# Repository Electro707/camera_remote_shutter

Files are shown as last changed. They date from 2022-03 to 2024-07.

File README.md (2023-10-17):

# Camera Remote Shutter Project
#### Rev 1.0-alpha

This is an open-source camera remote shutter.

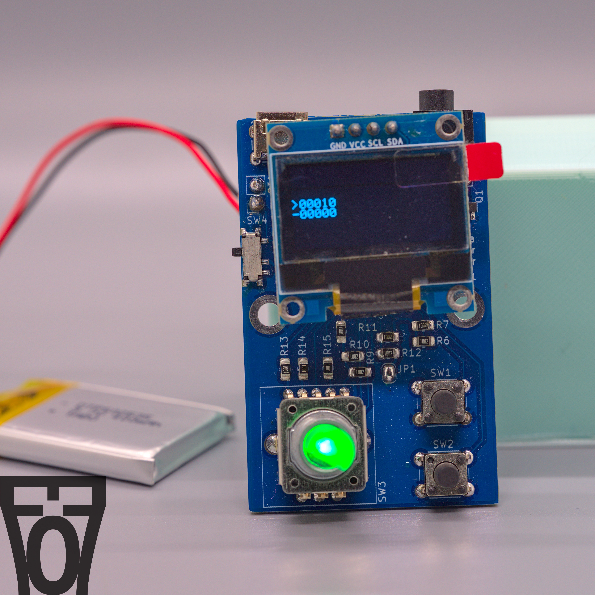
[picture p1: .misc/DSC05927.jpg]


## Enclosure
There is a work-in-progress enclosure for the PCB under the [CAD](CAD) folder. The enclosure is made with FreeCAD 0.20.

## Firmware
The firmware for this project is in the `AVR` folder. To build the code, simply run

```
make
```

This will generate a binary to upload to the MCU. To program the board, you can connect an Arduino Uno acting as an ISP device to the 3x2 connector on the board (J2). Then you can use the following make argument to upload with AVRDude. The port is asssumed to be `/dev/ttyUSB0`, so if that is different you can change the makefile.

```
make program
```

## KiCAD 3D Models
The 3D models for some components in the directory `PCB/3d_model/` are not included due to licensing reasons. You can grab the step files yourself and put it in that directory from the manufacturer. The models are
- 12CE3H26F12T24.stp
- CUI_DEVICES_SJ-2509N.step

# License
This project is licensed under GPLv3. See [LICENSE.md](LICENSE.md) for details.

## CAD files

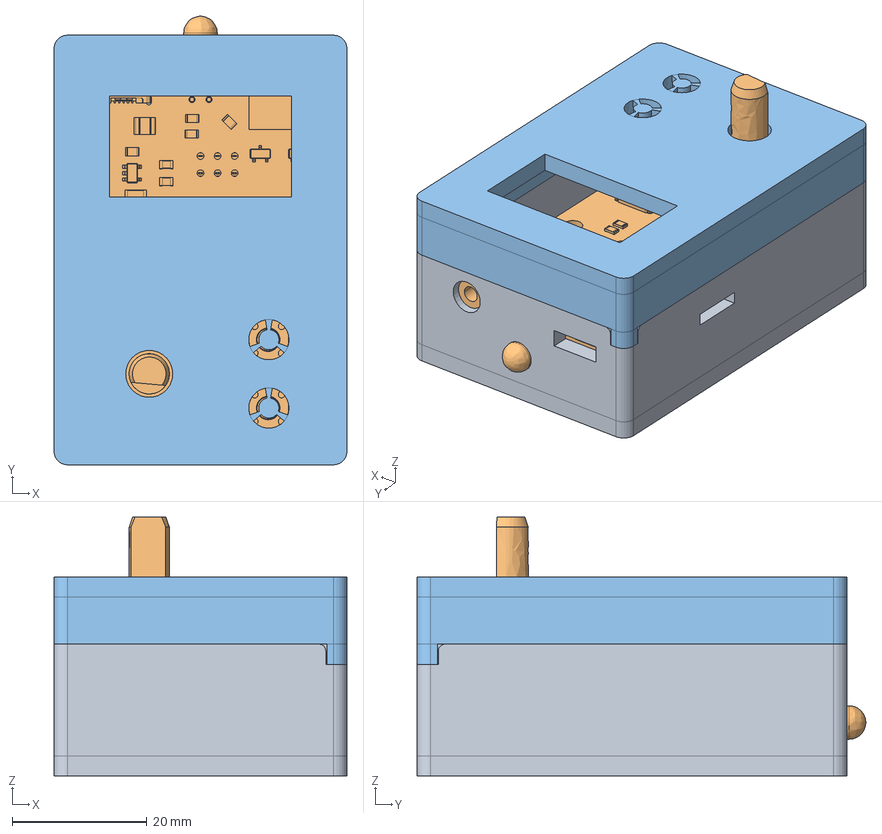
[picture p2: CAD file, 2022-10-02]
CAD/Assembly.FCStd
43.6 x 66.7 x 38.5 mm
MainBody_001
PCB1_001
TopCover_001

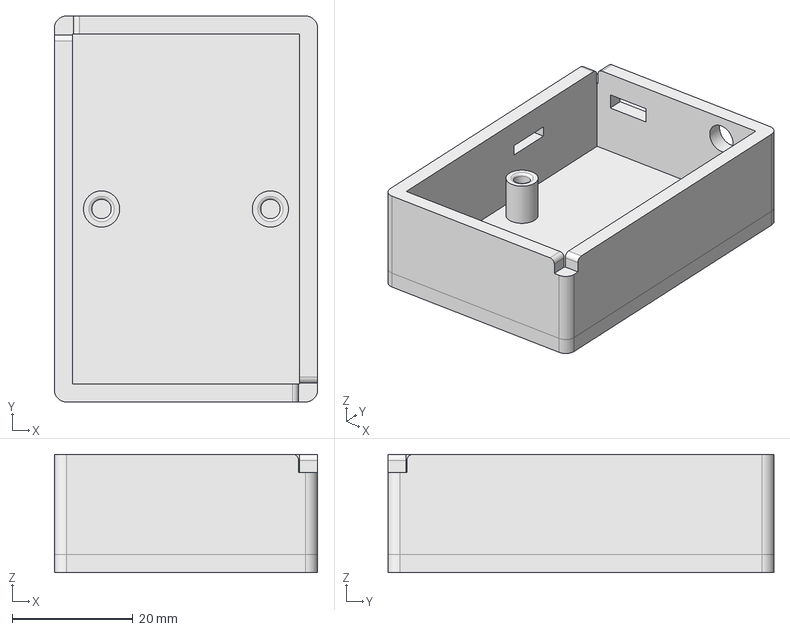
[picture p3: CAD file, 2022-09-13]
CAD/MainBody.FCStd
43.6 x 63.9 x 19.6 mm

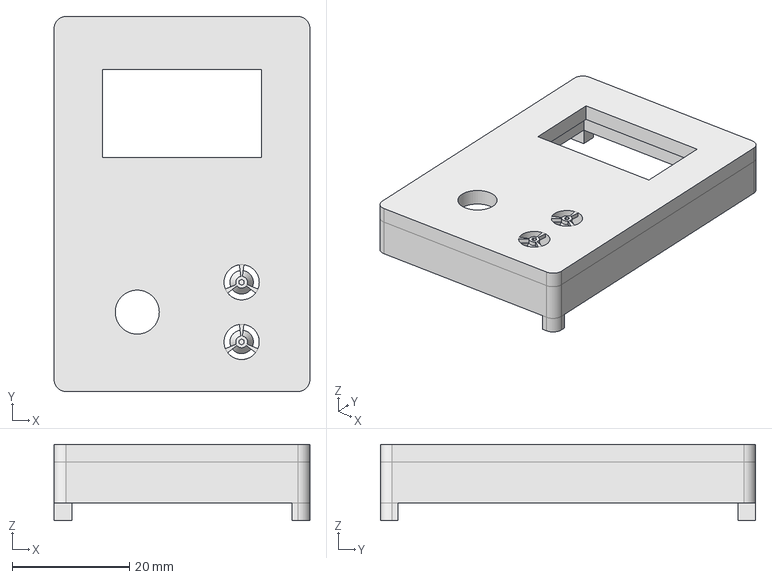
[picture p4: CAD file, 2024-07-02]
CAD/TopCover.FCStd
43.6 x 63.9 x 13.0 mm

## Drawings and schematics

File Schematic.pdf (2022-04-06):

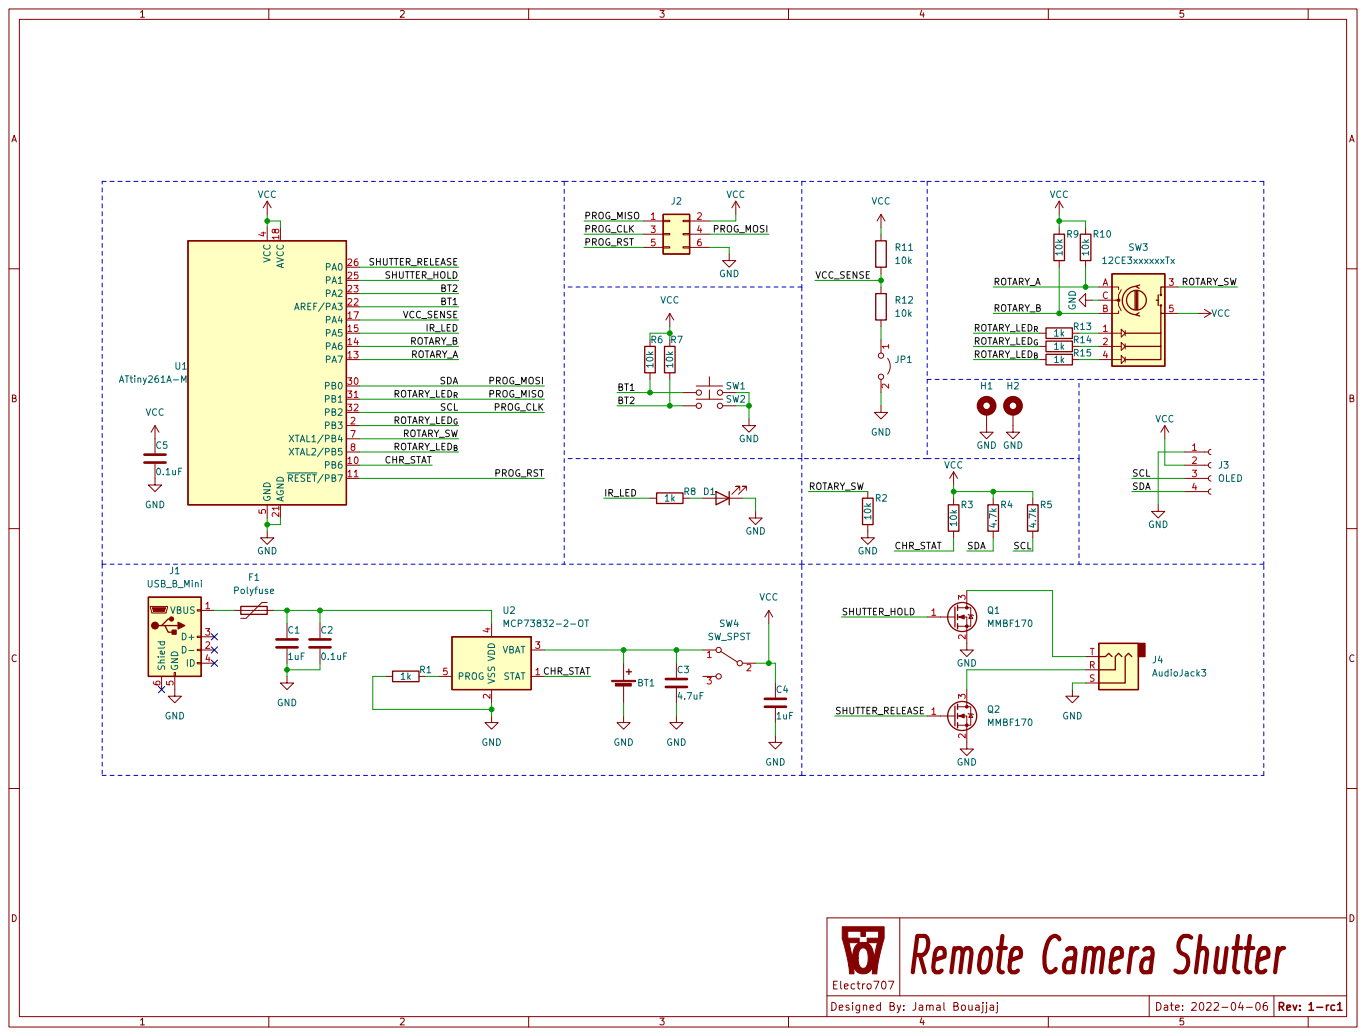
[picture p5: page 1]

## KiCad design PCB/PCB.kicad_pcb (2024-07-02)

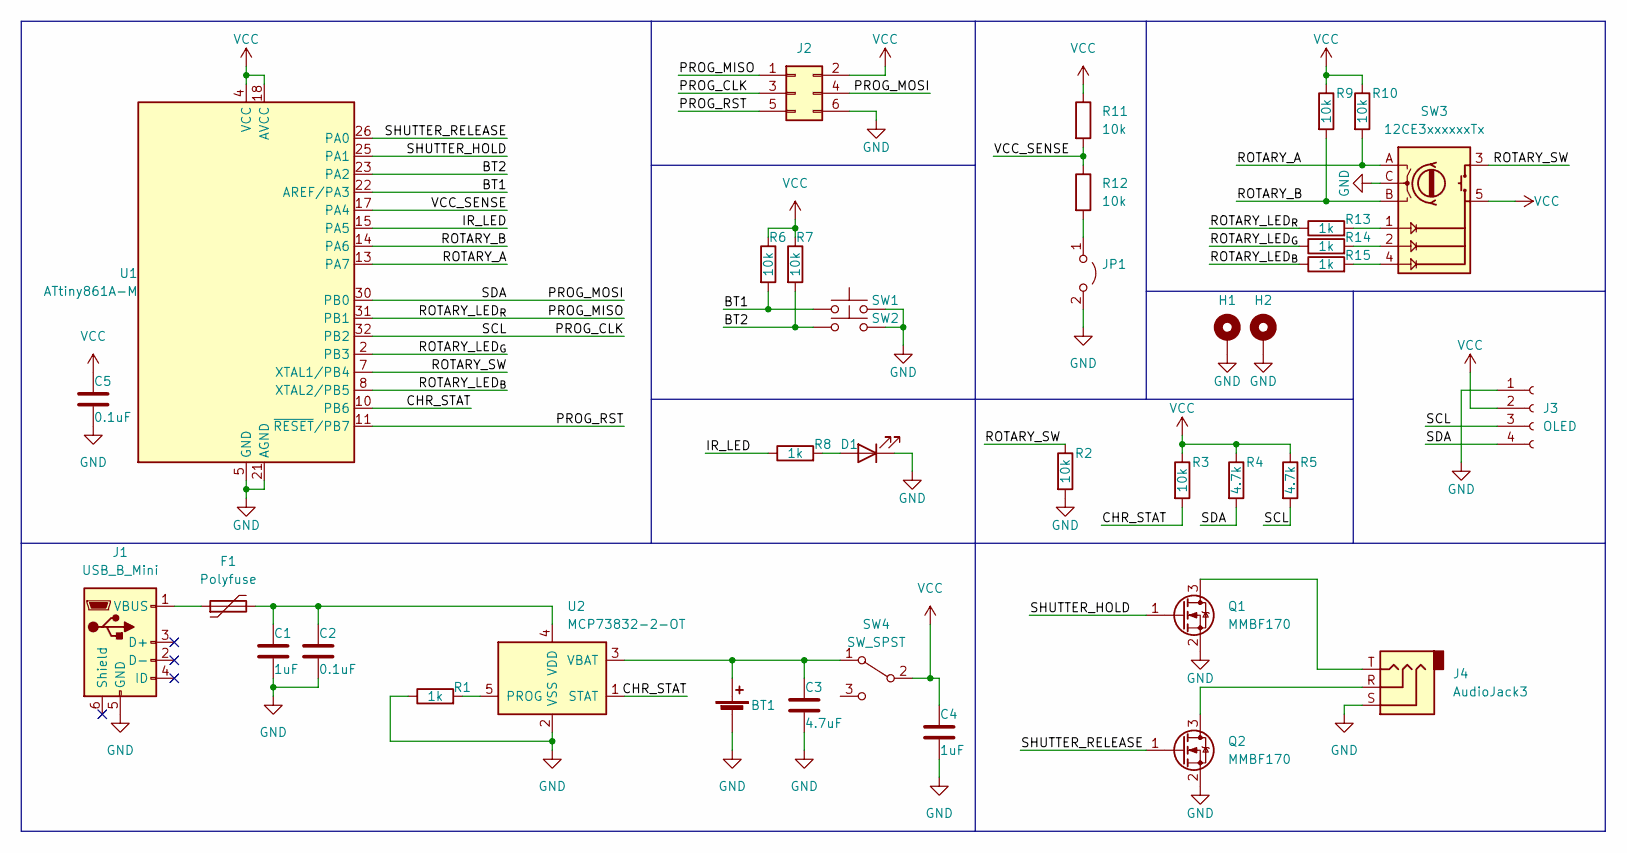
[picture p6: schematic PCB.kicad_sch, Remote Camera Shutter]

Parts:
BT1: Battery_Cell; PinSocket_1x02_P2.54mm_Vertical
C1, C4: 1uF; C_0805_2012Metric_Pad1.18x1.45mm_HandSolder
C2, C5: 0.1uF; C_0805_2012Metric_Pad1.18x1.45mm_HandSolder
C3: 4.7uF; C_1206_3216Metric_Pad1.33x1.80mm_HandSolder
D1: LED; LED_D5.0mm_Horizontal_O3.81mm_Z3.0mm
F1: Polyfuse; Fuse_1210_3225Metric_Pad1.42x2.65mm_HandSolder
H1, H2: MountingHole_Pad; MountingHole_3.2mm_M3_DIN965_Pad
J1: USB_B_Mini; USB_Micro-B_Wuerth_629105150521
J2: Conn_02x03_Odd_Even; PinSocket_2x03_P2.54mm_Vertical
J3: OLED; PinSocket_1x04_P2.54mm_Vertical
J4: AudioJack3; MJ1-2503A
JP1: Jumper_2_Open; SolderJumper-2_P1.3mm_Open_RoundedPad1.0x1.5mm
Q1, Q2: MMBF170; SOT-23
R1, R8, R13, R14, R15: 1k; R_0805_2012Metric_Pad1.20x1.40mm_HandSolder
R2, R3, R6, R7, R9, R10, R11, R12: 10k; R_0805_2012Metric_Pad1.20x1.40mm_HandSolder
R4, R5: 4.7k; R_0805_2012Metric_Pad1.20x1.40mm_HandSolder
SW1, SW2: SW_Push; SW_PUSH_6mm
SW3: 12CE3xxxxxxTx; 12CE3KxxxxxTx
SW4: SW_SPST; SW_SPDT_PCM12
U1: ATtiny861A-M; QFN-32-1EP_5x5mm_P0.5mm_EP3.1x3.1mm
U2: MCP73832-2-OT; SOT-23-5

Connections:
/BT1: R6.2, SW1.1, U1.22 (AREF/PA3)
/BT2: R7.2, SW2.1, U1.23 (PA2)
/CHR_STAT: R3.2, U1.10 (PB6), U2.1 (STAT)
/IR_LED: R8.1, U1.15 (PA5)
/PROG_CLK: J2.3, J3.3, R5.2, U1.32 (PB2)
/PROG_MISO: J2.1, R13.1, U1.31 (PB1)
/PROG_MOSI: J2.4, J3.4, R4.2, U1.30 (PB0)
/PROG_RST: J2.5, U1.11 (~RESET/PB7)
/ROTARY_A: R10.2, SW3.A, U1.13 (PA7)
/ROTARY_B: R9.2, SW3.B, U1.14 (PA6)
/ROTARY_LED_{B}: R15.1, U1.8 (XTAL2/PB5)
/ROTARY_LED_{G}: R14.1, U1.2 (PB3)
/ROTARY_SW: R2.1, SW3.3 (S1), U1.7 (XTAL1/PB4)
/SHUTTER_HOLD: Q1.1 (G), U1.25 (PA1)
/SHUTTER_RELEASE: Q2.1 (G), U1.26 (PA0)
/VCC_SENSE: R11.2, R12.1, U1.17 (PA4)
GND: BT1.2 (-), C1.2, C2.2, C3.2, C4.2, C5.2, D1.1 (K), H1.1, H2.1, J1.5 (GND), J2.6, J3.1, J4.S, JP1.2 (B), Q1.2 (S), Q2.2 (S), R1.1, R2.2, SW1.2, SW2.2, SW3.C, U1.5 (GND), U1.21 (AGND), U1.33 (GND), U2.2 (VSS)
unnamed: BT1.1 (+), C3.1, SW4.1 (A), U2.3 (VBAT)
unnamed: D1.2 (A), R8.2
unnamed: F1.1, J1.1 (VBUS)
unnamed: JP1.1 (A), R12.2
unnamed: J4.T, Q1.3 (D)
unnamed: J4.R, Q2.3 (D)
unnamed: R15.2, SW3.4 (L_B)
unnamed: R14.2, SW3.2 (L_G)
unnamed: R13.2, SW3.1 (L_R)
unnamed: R1.2, U2.5 (PROG)
unnamed: C1.1, C2.1, F1.2, U2.4 (VDD)
VCC: C4.1, C5.1, J2.2, J3.2, R3.1, R4.1, R5.1, R6.1, R7.1, R9.1, R10.1, R11.1, SW3.5 (COMM), SW4.2 (B), U1.4 (VCC), U1.18 (AVCC)

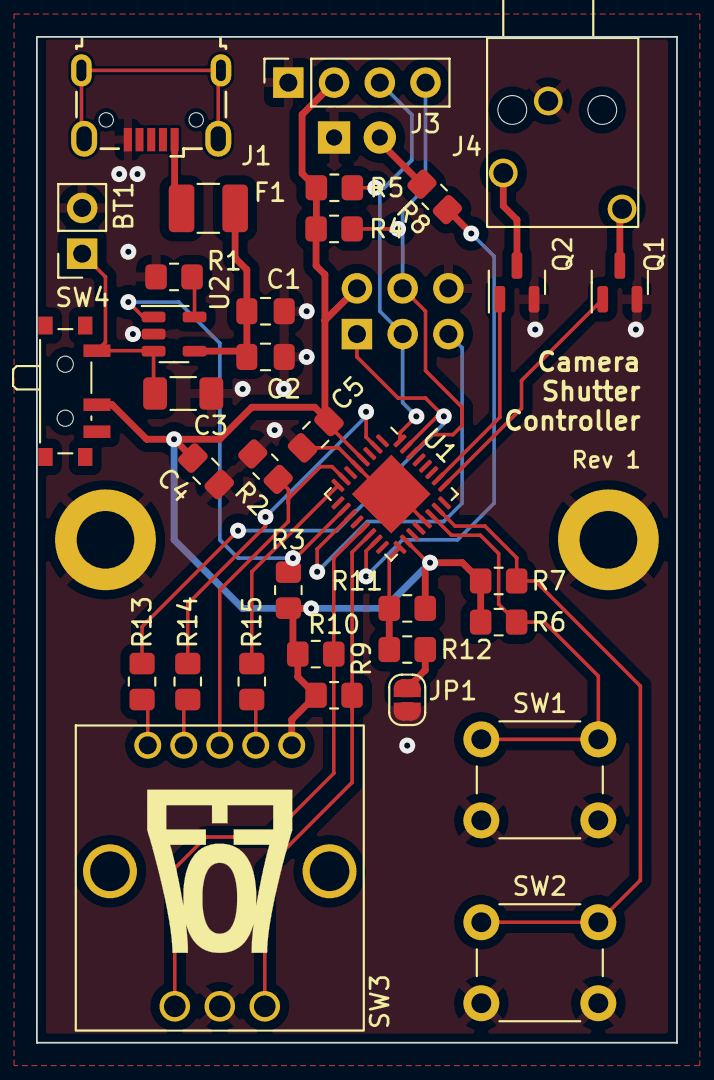
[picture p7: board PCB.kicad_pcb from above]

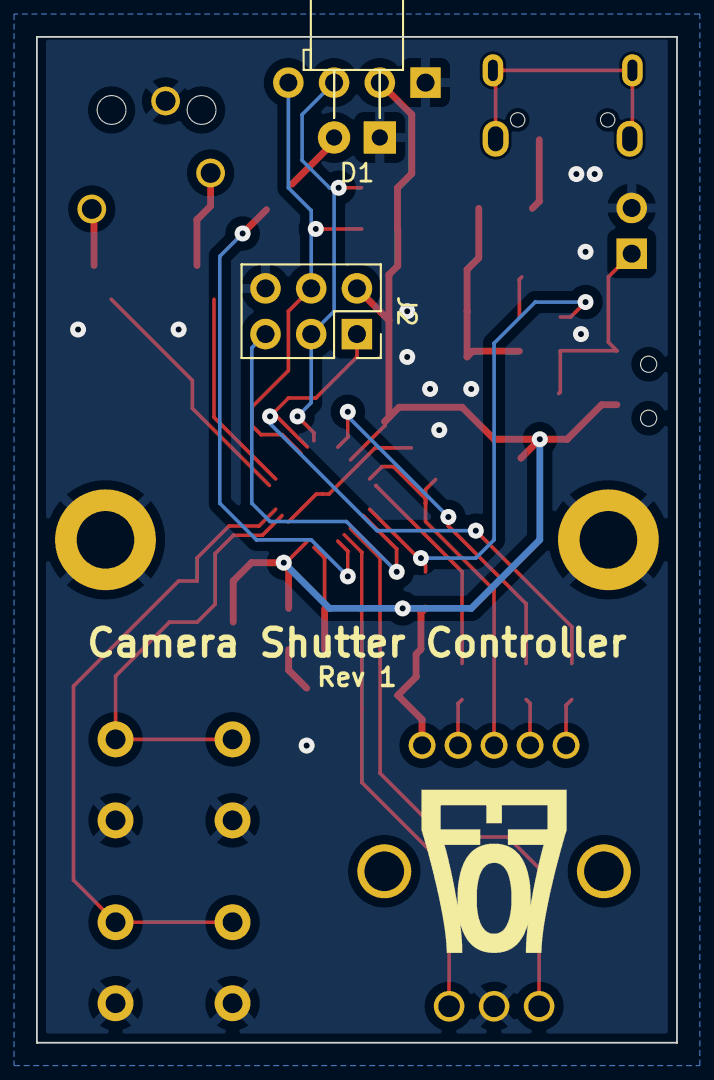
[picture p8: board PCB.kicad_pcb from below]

Board: 2 copper layers, 35.6 x 55.9 mm, 38 parts (2 on the bottom side), 29 nets.

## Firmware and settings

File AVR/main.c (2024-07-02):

/**
 * Camera Shutter Control Project
 * By Electro707, 2023
 *
 * This is the main firmware file for the camera shutter board.
 *
 * This program is free software: you can redistribute it and/or modify it under the terms of the
 * GNU General Public License as published by the Free Software Foundation, either version 3 of the
 * License, or (at your option) any later version.
 */
#define F_CPU 8000000       // CPU clock cycles
#define N_DIGITS    5

#include <stdbool.h>
#include <avr/io.h>
#include <util/delay.h>
#include <avr/interrupt.h>
#include <stdlib.h>
#include "USI_TWI_Master.h"
#include "oled.h"


/* LED Related Macros */
#define LED_PORT PORTB
#define LED_RED_PIN (1 << 1)
#define LED_GREEN_PIN (1 << 3)
#define LED_BLUE_PIN (1 << 5)
#define TURN_ON_RED_LED (LED_PORT &= ~LED_RED_PIN)
#define TURN_ON_GREEN_LED (LED_PORT &= ~LED_GREEN_PIN)
#define TURN_ON_BLUE_LED (LED_PORT &= ~LED_BLUE_PIN)
#define TURN_OFF_RED_LED (LED_PORT |= LED_RED_PIN)
#define TURN_OFF_GREEN_LED (LED_PORT |= LED_GREEN_PIN)
#define TURN_OFF_BLUE_LED (LED_PORT |= LED_BLUE_PIN)
#define TURN_OFF_ALL_LED TURN_OFF_RED_LED; TURN_OFF_GREEN_LED; TURN_OFF_BLUE_LED
#define TURN_ON_CYAN TURN_ON_GREEN_LED; TURN_ON_BLUE_LED
/* Rotary Encoder and Button Read Macros */
#define READ_ROTARY_ENCODER_BIT ((PINA >> 6) & 0b11)
#define READ_ROTARY_ENCODER_BUTTON ((PINB >> 4) & 0b1)
#define READ_TRIGGER_BUTTON ((PINA >> 2) & 0b1)
#define READ_MODE_BUTTON ((PINA >> 3) & 0b1)
/* Trigger Related Macros */
#define TRIGGER_ON PORTA |= (1 << 1); PORTA |= (1 << 0)
#define TRIGGER_OFF PORTA &= ~(1 << 1); PORTA &= ~(1 << 0)

#define RESET_TIMER TCNT0H = 0; TCNT0L = 0

typedef enum{
    ROTARY_ENCODER_ROT_NOTHING = 0,
    ROTARY_ENCODER_ROT_CW = 1,
    ROTARY_ENCODER_ROT_CCW = 2,
}RotaryEncoderRotation_e;

typedef enum{
    TRIGGER_MODE_STANDBY = 0,               // standby, doing nothing
    TRIGGER_MODE_ARM,                       // arming, i.e waiting for trigger
    TRIGGER_MODE_TRIGGERED,                 // triggered the camera
    TRIGGER_MODE_WAITING_FOR_NEXT_PIC,      // waiting for the next picture in a multi picture arm
    TRIGGER_MODE_END,                       // end of trigger
}TriggerMode_e;

typedef enum{
    VARIABLE_CHANGE_TRT = 0,
    VARIABLE_CHANGE_TT,
    VARIABLE_CHANGE_NPIC,
    VARIABLE_CHANGE_INVERV,
}ChangeVariable_e;

typedef struct{
    RotaryEncoderRotation_e dir;
    bool bt_press;   // true if we pressed on the rotary encoder
}RotaryEncoderStruct_s;

/**
 * All trigger settings
 */
typedef struct{
    int16_t tt;         // Time to Trigger
    int16_t trt;        // Trigger Duration
    int16_t n_pic;      // number of pictures for timelapse mode
    int16_t tmlps_interv;   // The interval in seconds between different timelapse
}ShutterTriggerVars_s;

/**
 * Any system/run-time config
 */
typedef struct{
    TriggerMode_e mode;                 // the current trigger state machine mode
    ChangeVariable_e selected_to_change;     // index to variable we selected to be changed
    uint8_t selected_digit;         // index to digit to be changed
    int16_t *var_to_change;        // pointer to variable to change
}SystemConfig_s;

const int16_t tens_radix[5] = {1, 10, 100, 1000, 10000};

uint8_t blinking_led_var = 0;       // Variable used for blinking an LED during pre-trigger time
uint8_t timer_counter = 0;          // Counter used to make TIMER0 count once a second

int currBattBar = -1;
uint8_t isCharging = false;

uint8_t flagUpdateTrigTime = false;

ShutterTriggerVars_s shutter_trigger = {0};
ShutterTriggerVars_s old_shutter_trigger = {0};
RotaryEncoderStruct_s encoder_vars;
SystemConfig_s sys;

int text_to_ascii(uint16_t n, char *text);
void update_sutter_trigger_time(void);
void increment_change_var(void);
void start_arming(void);

void updateBatteryLevel(void);
void update_batt_indicator(void);

int main(void){
    uint8_t mode_bt_press = 0;
    int16_t change_by;
    // Clear variables
    shutter_trigger.tt = 0;
    shutter_trigger.trt = 10;
    sys.mode = TRIGGER_MODE_STANDBY;
    sys.selected_to_change = VARIABLE_CHANGE_TRT;
    sys.var_to_change = &shutter_trigger.trt;
    encoder_vars.bt_press = 0;

    // Setup GPIO
    DDRA = 0b00100011;
    DDRB = 0b00101111;

    PORTA |= (0b11 << 6);

    // Setup Timer 0 as the main ticker counter
    // 8Mhz / 256 / 250 = 125 Hz
    OCR0A = 250;
    TCCR0A = 1;
    TCCR0B = 0b100;
    TIMSK |= 1 << OCIE0A;

    // Clear Rotary Encoder LEDs
    TURN_OFF_RED_LED;
    TURN_OFF_GREEN_LED;
    TURN_OFF_BLUE_LED;
    
    // Enable Pin Change Interrupt for the important pins
    GIMSK |= (1 << PCIE1);
//     PCMSK0 |= (1 << PCINT2) | (1 << PCINT3) | (1 << PCINT6) | (1 << PCINT7);
//     PCMSK1 |= (1 << PCINT12);
    PCMSK0 |= (1 << PCINT6) | (1 << PCINT7);

    // enable the battery ADC input, ADC3
    ADMUX = (1 << REFS1) | (0b00011);      // select 2.56v reference, set mux to single ended PA4
    ADCSRB = (1 << REFS2);          // ref for 2.56v. free running mode
    DIDR0 = (1 << ADC3D);                          // disable digital input (only used for analog)
    ADCSRA = (0b111 << 5);       // enable adc and start conversion
    //ADCSRA = (1 << 7);       // enable adc

    
    USI_TWI_Master_Initialise();
    oled_init();
    // oled_send_text("CAMERA SHUTTER", 0);
    // oled_send_text("CONTROLLER REV 0.1", 1);
    update_sutter_trigger_time();
    oled_send_text("Shutter Speed:", 0);
    oled_send_text("T- Trigger:", 2);
    oled_send_text("Timelapse:", 4);

    oled_send_text_offset("# Pics:", 5, 0);
    oled_send_text_offset("Interv:", 5, 64);
    
    // Enable interrupts
    sei();
    
    while(1){
        _delay_ms(10);
        updateBatteryLevel();
        // only update if we are in standby
        if(sys.mode == TRIGGER_MODE_STANDBY){
            // if we turn the rotary encoder
            if(encoder_vars.dir != ROTARY_ENCODER_ROT_NOTHING){
                change_by = tens_radix[sys.selected_digit];
                if(encoder_vars.dir == ROTARY_ENCODER_ROT_CW){
                    TURN_ON_RED_LED;
                    TURN_OFF_GREEN_LED;
                    *sys.var_to_change += change_by;
                }
                else if(encoder_vars.dir ==ROTARY_ENCODER_ROT_CCW){
                    TURN_ON_GREEN_LED;
                    TURN_OFF_RED_LED;
                    *sys.var_to_change -= change_by;
                    // special case for trt were we are capping it at 1
                    if(shutter_trigger.trt < 1)
                        shutter_trigger.trt = 1;
                    // cap any values at 0
                    if(*sys.var_to_change < 0)
                        *sys.var_to_change = 0;
                }
                update_sutter_trigger_time();
                // Clear this variable after we are done with it
                encoder_vars.dir = ROTARY_ENCODER_ROT_NOTHING;
            }
            // if we press the trigger button, change MODE and start the arming
            if(READ_TRIGGER_BUTTON == 0){
                start_arming();
            }
            // if we press the mode button, switch modes
            if(READ_MODE_BUTTON == 0 && mode_bt_press == 0){
                mode_bt_press = 1;
                increment_change_var();
            }
            else if(READ_MODE_BUTTON == 1 && mode_bt_press){
                mode_bt_press = 0;
            }
            // if we press the rotary encoder button, switch what value we are changing
            if(READ_ROTARY_ENCODER_BUTTON == 1 && encoder_vars.bt_press == 0){
                encoder_vars.bt_press = 1;
                sys.selected_digit += 1;
                if(sys.selected_digit >= N_DIGITS){
                    sys.selected_digit = 0;
                }
                update_sutter_trigger_time();
            }
            // down-press on rotary encoder button
            else if(READ_ROTARY_ENCODER_BUTTON == 0 && encoder_vars.bt_press == 1){
                encoder_vars.bt_press = 0;
            }
        }
        if(flagUpdateTrigTime){
            flagUpdateTrigTime = false;
            update_sutter_trigger_time();
        }
    }
}

void start_arming(void){
    // check that interval time, if npic != 0, is greater than trt
    if(shutter_trigger.n_pic != 0){
        if(shutter_trigger.tmlps_interv < (shutter_trigger.trt+shutter_trigger.tt)){
            return;
        }
    }

    memcpy(&old_shutter_trigger, &shutter_trigger, sizeof(shutter_trigger));
    blinking_led_var = 0;
    timer_counter = 0;
    RESET_TIMER;
    TURN_OFF_ALL_LED;
    // if(shutter_trigger.tt == 0){
        // TRIGGER_ON;
        // sys.mode = TRIGGER_MODE_TRIGGERED;
    // } else {
        sys.mode = TRIGGER_MODE_ARM;
    // }
}

/**
 * Gets called when we want to increment what variable we are changing
 */
void increment_change_var(void){
    switch (sys.selected_to_change){
    case VARIABLE_CHANGE_TRT:
        sys.selected_to_change = VARIABLE_CHANGE_TT;
        sys.var_to_change = &shutter_trigger.tt;
        break;
    case VARIABLE_CHANGE_TT:
        sys.selected_to_change = VARIABLE_CHANGE_NPIC;
        sys.var_to_change = &shutter_trigger.n_pic;
        break;
    case VARIABLE_CHANGE_NPIC:
        sys.selected_to_change = VARIABLE_CHANGE_INVERV;
        sys.var_to_change = &shutter_trigger.tmlps_interv;
        break;
    case VARIABLE_CHANGE_INVERV:
        sys.selected_to_change = VARIABLE_CHANGE_TRT;
        sys.var_to_change = &shutter_trigger.trt;
        break;
    }
    update_sutter_trigger_time();
}

/**
 * Updates the display with the current trigger times
 */
void update_sutter_trigger_time(void){
    char text[7];
    int8_t underscore_digit;

    underscore_digit = 0xFF;
    text_to_ascii(shutter_trigger.trt, text);
    if(sys.selected_to_change == VARIABLE_CHANGE_TRT){
        underscore_digit = N_DIGITS-sys.selected_digit-1;
    }
    oled_send_text_underscore(text, 1, underscore_digit);

    underscore_digit = 0xFF;
    text_to_ascii(shutter_trigger.tt, text);
    if(sys.selected_to_change == VARIABLE_CHANGE_TT){
        underscore_digit = N_DIGITS-sys.selected_digit-1;
    }
    oled_send_text_underscore(text, 3, underscore_digit);

    underscore_digit = 0xFF;
    text_to_ascii(shutter_trigger.n_pic, text);
    if(sys.selected_to_change == VARIABLE_CHANGE_NPIC){
        underscore_digit = N_DIGITS-sys.selected_digit-1;
    }
    oled_send_text_underscore(text, 6, underscore_digit);

    underscore_digit = 0xFF;
    text_to_ascii(shutter_trigger.tmlps_interv, text);
    if(sys.selected_to_change == VARIABLE_CHANGE_INVERV){
        underscore_digit = N_DIGITS-sys.selected_digit-1;
    }
    oled_send_chars(text, 6, 64, underscore_digit);
}

/**
 * Updates the current battery indicator to what it is
 */
void update_batt_indicator(void){
    uint8_t batt[12];       // the battery shall be 12 pixels long
    uint8_t *battP = batt;

    *battP++ = 0xFF;     // start of battery symbol
    for(uint8_t c=0;c<8;c++){
        if(isCharging){
            *battP = 0xA5;
        } else {
            if(c < (currBattBar << 1)){
                *battP = 0xFF;
            } else {
                *battP = 0x81;
            }
        }
        battP++;
    }
    *battP++ = 0xFF;
    *battP++ = 0x3C;
    *battP++ = 0x18;

    oled_send_buff(batt, 12, 0, 128-12);
}

/**
 * Converts a number to a string
 *
 * todo: rename function
 */
int text_to_ascii(uint16_t n, char *text){
    for(int i=0;i<=6;i++){text[i] = 0;}
    uint8_t text_len = N_DIGITS-1;
    while(1){
        text[text_len] = (n % 10) + 0x30;
        n /= 10;
        if(text_len-- == 0){
            break;
        }
    }
    return text_len;
}

void tmp(uint16_t r){
    char text[20];
    text_to_ascii(r, text);
    oled_send_text(text, 2);
}

/**
 * Updates the battery indicator from the VCC measured voltage
 *
 * the ADC units are
 *      meas(V/unit) = ADC * 2.56 * 2 / 1024
 *      meas(V/unit) = ADC * 0.005
 * so each ADC count is equal to 5mV
 *
 * Then we covert it to an approximate battery bar level
 *      >4.0v       (800)       -> 4 bar (full)
 *      4.0v - 3.7v (800 740)  -> 3 bar
 *      3.7v - 3.5v (740-700)  -> 2 bar
 *      3.5v - 3.3v (700-660)  -> 1 bar
 *      <3.3v (660)            -> 0 bar (empty)
 *
 * we add some hysterysis (20 counts?) so that the results don't jump back and forth
 */
void updateBatteryLevel(void){
    static int lastStateADC = 0;
    static int lastChargeState = false;
    int newBatteryBar;
    uint16_t res;

    if((PINB & (1 << 6)) == 0){
        lastChargeState = true;
    } else{
        lastChargeState = false;
    }

    if(isCharging != lastChargeState){
        isCharging = lastChargeState;
        update_batt_indicator();
    }

    if(isCharging){
        return;
    }

    if((ADCSRA & (1 << ADIF)) == 0){
        return;
    }
    res = ((uint16_t)ADCH << 8) | ADCL;           // get our results
    ADCSRA |= (1 << ADIF);

    if(res >= 800){
        newBatteryBar = 4;
    } else if(res < 800 && res >= 740){
        newBatteryBar = 3;
    } else if(res < 740 && res >= 700){
        newBatteryBar = 2;
    } else if(res < 700 && res >= 660){
        newBatteryBar = 1;
    } else if(res < 660){
        newBatteryBar = 0;
    }

    // tmp(res);

    if(newBatteryBar != currBattBar){
        // only update if we moved over by more 30 ADC counts than the last change reading
        if(abs(res - lastStateADC) > 30){
            lastStateADC = res;
            currBattBar = newBatteryBar;
            update_batt_indicator();
        }
    }
}

/**
 * Interrupt for timer. This gets triggered once every 1/125 seconds
 */
ISR(TIMER0_COMPA_vect){
    // Only actually do stuff here once the counter reaches one second
    if(++timer_counter != 125){return;}else{timer_counter = 0;}        

    switch(sys.mode){
        case TRIGGER_MODE_ARM:
            blinking_led_var = !blinking_led_var;
            if(blinking_led_var){TURN_ON_CYAN;}else{TURN_OFF_ALL_LED;}
            if(shutter_trigger.tt != 0){shutter_trigger.tt--;}
            if(shutter_trigger.tmlps_interv != 0){shutter_trigger.tmlps_interv--;}
            if(shutter_trigger.tt == 0){
                // TRIGGERED
                TRIGGER_ON;
                sys.mode = TRIGGER_MODE_TRIGGERED;
            }
            break;
        case TRIGGER_MODE_TRIGGERED:
            TURN_ON_BLUE_LED;
            shutter_trigger.trt--;
            if(shutter_trigger.tmlps_interv != 0){shutter_trigger.tmlps_interv--;}
            if(shutter_trigger.trt == 0){
                if(shutter_trigger.n_pic != 0){
                    sys.mode = TRIGGER_MODE_WAITING_FOR_NEXT_PIC;
                    shutter_trigger.n_pic--;
                } else {
                    // Trigger has stopped
                    sys.mode = TRIGGER_MODE_END;
                }
                
            }
            break;
        case TRIGGER_MODE_WAITING_FOR_NEXT_PIC:
            TRIGGER_OFF; TURN_OFF_ALL_LED;
            if(shutter_trigger.tmlps_interv == 0){
                shutter_trigger.trt = old_shutter_trigger.trt;
                shutter_trigger.tt = old_shutter_trigger.tt;
                if(shutter_trigger.tt == 0){
                    TRIGGER_ON;
                    sys.mode = TRIGGER_MODE_TRIGGERED;
                } else {
                    sys.mode = TRIGGER_MODE_ARM;
                }
            } else {
                shutter_trigger.tmlps_interv--;
            }
            break;
        case TRIGGER_MODE_END:
            TRIGGER_OFF;
            TURN_OFF_ALL_LED;
            memcpy(&shutter_trigger, &old_shutter_trigger, sizeof(shutter_trigger));
            sys.mode = TRIGGER_MODE_STANDBY;
            break;
        default:
            return; // intentional as we don't want to update the screen if not in picture taking mode
    }

    flagUpdateTrigTime = true;
}

/**
 * Interrupt for PortC, which is only for the rotary encoder
 */
ISR(PCINT_vect){
    static uint8_t pvcv;       // Previous Value (XX) and Current Value (YY), 0bXXYY
    // static uint8_t last_val;   // the last rotary encoder pin values

    if(encoder_vars.dir != ROTARY_ENCODER_ROT_NOTHING){
        GIFR |= (1 << PCIF);
        return;
    }
    // GIMSK &= ~(1 << PCIE1);
    // _delay_loop_2(7500);
    _delay_loop_2(150);

    uint8_t r = READ_ROTARY_ENCODER_BIT;
    // only update if the value of the rotary encoder has changed
    // todo: wouldn't this always be the case anyways due to the interrupt?? test without
    //if(r != encoder_vars.last_val){
    //    encoder_vars.last_val = r;
    pvcv = ((pvcv << 2) | r) & 0x0F;

    switch(pvcv){
        // case 0b0001:
        case 0b1000:
        case 0b0111:
        // case 0b1110:
            encoder_vars.dir = ROTARY_ENCODER_ROT_CW;
            // switchDebounce = 10;
            break;
        // case 0b0010:
        case 0b0100:
        case 0b1011:
        // case 0b1101:
            encoder_vars.dir = ROTARY_ENCODER_ROT_CCW;
            // switchDebounce = 10;
            break;
    }
    //}
    // clear the interrupt flag for PCIF
    GIFR |= (1 << PCIF);

}

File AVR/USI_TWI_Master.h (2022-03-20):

/*****************************************************************************
*
* Atmel Corporation
*
* File              : USI_TWI_Master.h
* Date              : $Date: 2016-7-15 $
* Updated by        : $Author: Atmel $
*
* Support mail      : avr@atmel.com
*
* Supported devices : All device with USI module can be used.
*                     The example is written for the ATmega169, ATtiny26 and ATtiny2313
*
* AppNote           : AVR310 - Using the USI module as a TWI Master
*
* Description       : This is an implementation of an TWI master using
*                     the USI module as basis. The implementation assumes the AVR to
*                     be the only TWI master in the system and can therefore not be
*                     used in a multi-master system.
* Usage             : Initialize the USI module by calling the USI_TWI_Master_Initialise()
*                     function. Hence messages/data are transceived on the bus using
*                     the USI_TWI_Start_Transceiver_With_Data() function. If the transceiver
*                     returns with a fail, then use USI_TWI_Get_Status_Info to evaluate the
*                     couse of the failure.
*
****************************************************************************/
#if __GNUC__
#ifndef F_CPU
#define F_CPU 8000000
#endif
#include <avr/io.h>
#include <util/delay.h>
#endif
//********** Defines **********//
// Defines controlling timing limits
#define TWI_FAST_MODE

#define SYS_CLK 8000.0 // [kHz]

#ifdef TWI_FAST_MODE                            // TWI FAST mode timing limits. SCL = 100-400kHz
#define T2_TWI ((SYS_CLK * 1300) / 1000000) + 1 // >1,3us
#define T4_TWI ((SYS_CLK * 600) / 1000000) + 1  // >0,6us

#else                                           // TWI STANDARD mode timing limits. SCL <= 100kHz
#define T2_TWI ((SYS_CLK * 4700) / 1000000) + 1 // >4,7us
#define T4_TWI ((SYS_CLK * 4000) / 1000000) + 1 // >4,0us
#endif

// Defines controling code generating
//#define PARAM_VERIFICATION
//#define NOISE_TESTING
//#define SIGNAL_VERIFY

// USI_TWI messages and flags and bit masks
//#define SUCCESS   7
//#define MSG       0
/****************************************************************************
  Bit and byte definitions
****************************************************************************/
#define TWI_READ_BIT 0 // Bit position for R/W bit in "address byte".
#define TWI_ADR_BITS 1 // Bit position for LSB of the slave address bits in the init byte.
#define TWI_NACK_BIT 0 // Bit position for (N)ACK bit.

#define USI_TWI_NO_DATA 0x00           // Transmission buffer is empty
#define USI_TWI_DATA_OUT_OF_BOUND 0x01 // Transmission buffer is outside SRAM space
#define USI_TWI_UE_START_CON 0x02      // Unexpected Start Condition
#define USI_TWI_UE_STOP_CON 0x03       // Unexpected Stop Condition
#define USI_TWI_UE_DATA_COL 0x04       // Unexpected Data Collision (arbitration)
#define USI_TWI_NO_ACK_ON_DATA 0x05    // The slave did not acknowledge  all data
#define USI_TWI_NO_ACK_ON_ADDRESS 0x06 // The slave did not acknowledge  the address
#define USI_TWI_MISSING_START_CON 0x07 // Generated Start Condition not detected on bus
#define USI_TWI_MISSING_STOP_CON 0x08  // Generated Stop Condition not detected on bus

// Device dependant defines
#define DDR_USI DDRB
#define PORT_USI PORTB
#define PIN_USI PINB
#define PORT_USI_SDA PORTB0
#define PORT_USI_SCL PORTB2
#define PIN_USI_SDA PINB0
#define PIN_USI_SCL PINB2


// General defines
#define TRUE 1
#define FALSE 0

#if __GNUC__
#define DELAY_T2TWI (_delay_us(T2_TWI / 4))
#define DELAY_T4TWI (_delay_us(T4_TWI / 4))
#else
#define DELAY_T2TWI (__delay_cycles(T2_TWI))
#define DELAY_T4TWI (__delay_cycles(T4_TWI))
#endif
//********** Prototypes **********//

void USI_TWI_Master_Initialise(void);
#ifndef __GNUC__
__x // AVR compiler
#endif
    unsigned char
    USI_TWI_Start_Transceiver_With_Data(unsigned char *, unsigned char);

unsigned char USI_TWI_Get_State_Info(void);

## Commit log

2022-04-06 Updated schematic
    [PCB.kicad_sch]
2022-04-18 Added a WIP CAD model
    [MainBody.FCStd]
2022-09-13 Finished initial design of enclosure. Added dimentions to PCB
    [Assembly.FCStd, MainBody.FCStd, PCB.kicad_pcb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]
2022-10-02 Updated top cover. Added picture
    [Assembly.FCStd, TopCover.FCStd]
2024-07-02 Updated? pcb files. Modification to CAD. updated gitignore
    [PCB.kicad_pcb, PCB.kicad_sch, TopCover.FCStd]
2024-07-02 added battery level indicator trigger does both pins, which is needed for some cameras rotary encoder improvements more firmware improvements
